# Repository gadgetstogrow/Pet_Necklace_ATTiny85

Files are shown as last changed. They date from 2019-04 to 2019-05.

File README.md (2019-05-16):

# USE THE RECONFIGURATION CODE - KG 5-16-19 (WILL MERGE BEFORE PUBLISHING)

# LED Pet Necklace with the ATTiny85

This project is useful for those looking to journey outside the cozy confines of the Arduino Uno and on to other AVRs. The ATTiny85 is a great place to start. The example code was first developed using Atmel Studio 7 with the help of an AVR Dragon for debugging. Don't worry, It will compile and upload using the Arduino IDE. A complete and detailed tutorial can be found on my project page on [Hackster.io] (https://www.hackster.io/GadgetsToGrow/)

## 3D Printed Parts

The 3D parts that make up the enclosure of this project were designed using [FreeCAD](https://www.freecadweb.org/) all other materials needed are available online or at your local hardware store.

## Concepts discussed on Hackster.io 

-Direct Register Manipulation - discover and experiment with the DDRB, PINB, PORTB and other registers of the ATTiny85 to control input and output instead of using the familiar pinMode() and digitalWrite() methods. We'll also be using register manipulation for Timer/Counter1 and the Analog to Digital Converter (ADC).

-Power Management - we'll use a coin cell battery for this project, so reducing unnecessary power consumption is paramount. (e.g. sleep mode and turning off peripherals we're not using).

-Pin Change Interrupts - the Tilt Sensor is used to wake up the ATTiny85 from sleep mode via a pin change interrupt using the PCINT0 vector. Why use power for the MCU and LEDs when your pet is sleeping or still?

-ADC Setup and Measurement - we'll leave analogRead() behind, and control the ADC to measure ambient light level through direct register control. You'll see how to handle a 10-bit value, and how to enable and disable the ADC for power management.
Timer/Counter1 - instead of tying up processor time with the mundane task of blinking LEDs at a specific interval, we'll use TImer/Counter1 to handle this task and explore the benefits of this "set it and forget it" methodology.

### Prerequisites

You'll need to use a USBTiny programmer, the ArduinoISP example code or similar method for programming an ATTiny85. These methods are beyond the scope of this project, but a vast amount of instruction is available online.
With that said, if you're planning on working with AVRs other than the Arduino (especially ones without a UART (like the ATTiny85) I'd highly recommend taking a look at Atmel Studio and a compatible programmer/debugger. Atmel Studio is free, and you can pick up an AVR Dragon on Ebay for < $50.

## License

This project is licensed under the GNU License - see the [LICENSE.md](LICENSE.md) file for details

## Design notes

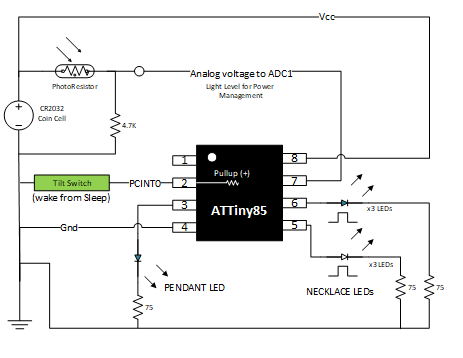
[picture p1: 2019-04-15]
Logic Flow Diagrams/Blinky Flashy Pet Collar Block Diagram.png

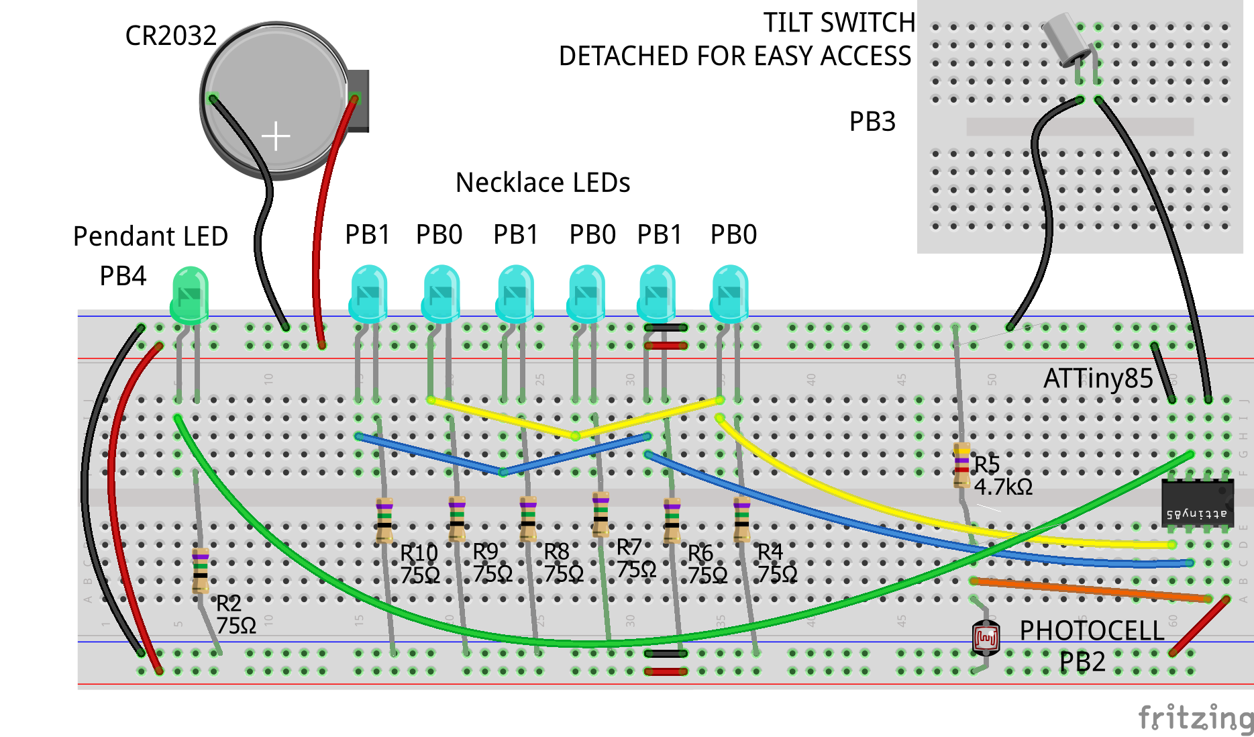
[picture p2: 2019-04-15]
Fritzing/Pet_Necklace_ATTiny85_Image.png

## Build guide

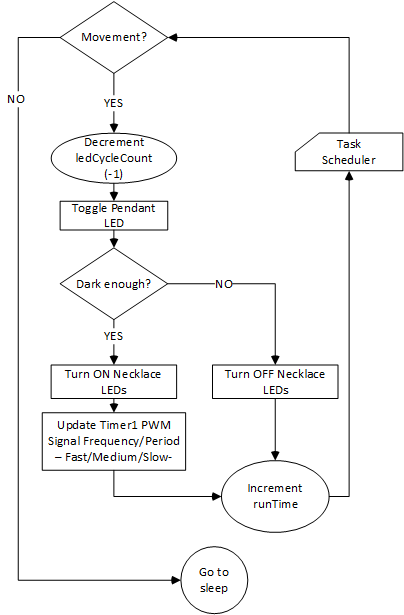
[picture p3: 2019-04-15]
Logic Flow Diagrams/Theory of Operation.png

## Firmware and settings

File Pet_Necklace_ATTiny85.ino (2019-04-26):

/****************************************************************************
 *  Project:	Pet_Necklace_ATTiny85.ino
 *	Version:	1.4.0
 *  Contact:	Kevin Gagnon
 *	Twitter:	@GadgetsToGrow
 *
 *  YouTube:	https://www.youtube.com/channel/UCseG_fDVFWgDqoBSpghMIPg
 *	  
 *  Date:		4-15-2019
 *  
 *  Purpose:	A *glamorous* blinking pet necklace using the ATTiny85. 
 *				Blinking occurs when the tilt/inclination sensor detects
 *				movement and only turns on the main LEDs (6) in the collar
 *				portion of the necklace when the light level is at a specified
 *				threshold. There is a pendant LED that will flash if there is
 *				movement, independent of the light level. When no movement is
 *				detected, the ATTiny85 is put into power down sleep mode and
 *				awaits an interrupt from the tilt sensor.
 *			
 *  Tutorial:	
 *
 *  Source:		
 * 
 *  ATTiny85 PINOUT *********************************************************
 *
 *	SOFTWARE	PHYSICAL
 *	PIN			PIN			PURPOSE											
 *	-------------------------------------------------------------------------
 *	PB0 - PB1:	5-6			Blink the 6 Necklace LEDs
 *  PB2:		7			PhotoCell (Power Management) Is it dark enough?	
 *	PB3:		2			Pin Change Interrupt (PCINT0_vect/PCINT3)
 *	PB4:		3			Pendant LED							
 *
 ****************************************************************************/

#include <avr/sleep.h>
#include <avr/io.h>
#include <avr/interrupt.h>

// ***
// *** Task Scheduler library
// ***
#include "Task.h"
#include "TaskScheduler.h"

// ***
// *** Application Configuration File (e.g. Pin Numbers, CPU Clock Frequency, etc.)
// ***
// ***
#include "Config.h"

// ***
// *** Application specific tasks
// ***
// Note: Necklace LEDs will only be turned on at certain light level threshold.
#include "Photocell.h"

// --------------------------------------------------------------------------------------------
// Define the AppManager Class as type: TimedTask
//
// Reads the ledCycleCount variable (incremented by ISR(PCINT0_vect) every 100ms
// via the tilt sensor attached to Pin PB3. If the value is greater than zero
// (activity sensed) the AppManager Task (depending on light level) executes LED routines.
//
// If ledCycleCount is zero (no activity/lazy pet), it puts the ATTiny85 to sleep and waits to be interrupted again. 
//
// --------------------------------------------------------------------------------------------
class AppManager : public TimedTask
{
	public:
		AppManager( uint16_t _readRate,	Photocell *_ptrPhotocell);
		//Task Scheduler-------------------------------------------------------------------------------			
		virtual void run(uint32_t now);
	
	private:
		uint8_t readRate; 						// Rate to read the Tilt Sensor
		
		//Tilt Sensor Related--------------------------------------------------------------------------
		void initPinChangeInterrupt();			// Enables the Pin Change Interrupt

		//ADC Related----------------------------------------------------------------------------------
		void enableADC(bool _enabled);			// Enable/Disable the ADC
		bool isLightLevelOk();					// Compare Light Level reading to LIGHT_THRESHOLD
		
		//Pendant LED----------------------------------------------------------------------------------
		void togglePendantLED();				//Toggle the Pendant LED on each read of Tilt Sensor
												//independent of the current Light Level.
		
		//Necklace LEDs--------------------------------------------------------------------------------
		void clearTimer1Config();
		void updateTimer1Config(uint8_t _ledCycleCount);	// Timer1: Change/Update Timer1 Mode/Rate
		void initAlternatingBlink_PWM();

		//Global Control-------------------------------------------------------------------------------
		void enableGlobalInterrupts(bool _enabled);		// Enable/Disable Global Interrupts sei/cli
		void enableNecklaceLEDOutput(bool _enabled);	// Enable/Disable Output for LEDs in Necklace
		void enablePendantLEDOutput(bool _enabled);		// Enable/Disable Output for the Pendant LED
		void goToSleep();								// Turn off peripherals and go to sleep...ZZzz
		
		//App Task Control Pointers-------------------------------------------------------------
		Photocell *ptrPhotocell;

};

//-------------------------------------------------------------------------------------------
// AppManager Constructor - Initializes the TimedTask to control the current application
//-------------------------------------------------------------------------------------------
AppManager::AppManager( uint16_t _readRate, Photocell *_ptrPhotocell)
	
	: TimedTask(millis()),
	readRate(_readRate),
	ptrPhotocell(_ptrPhotocell)

{
	
	// ***
	// *** Enable Tilt Sensor Pin Change Interrupt on PB3
	// ***
	initPinChangeInterrupt();

	// ***
	// *** Enable Global Interrupts - sei();
	// ***
	enableGlobalInterrupts(true);
	
	
	// ***
	// *** Enable Necklace LED Output (PB0/PB1)
	// ***
	enableNecklaceLEDOutput(true);
	
	// ***
	// *** Enable Pendant LED Output (PB4)
	// ***
	enablePendantLEDOutput(true);
		
	// ***
	// *** Clear Timer1 Configuration Settings
	// ***
	clearTimer1Config();
	
	// ***
	// *** Initialize Timer1 to handle LED control
	// ***
	initAlternatingBlink_PWM();

}

//-------------------------------------------------------------------
// Main AppManager Routine
//-------------------------------------------------------------------
void AppManager::run(uint32_t now)
{
	if(ledCycleCount > 1) //Movement/Awake - performing application functions
	{
		//Decrement  the ledCycleCount, when it finally reaches zero, go to sleep
		ledCycleCount--;

			// Toggle the LED in the Pendant. This is good for debugging and battery
			// monitoring even if the light level is too high for the Necklace LEDs.
			togglePendantLED();

			// Check the Light Level against LIGHT_THRESHOLD
			if(isLightLevelOk())
			{
				
				// Enable the Necklace LEDs on PB0 and PB1.
				enableNecklaceLEDOutput(true);
				
				// Update the Output Compare Registers (OCR1A and OCR1C) depending
				// on the current value of ledCycleCount to change the frequency and
				// period of outputs PB1/OC1A and PB0/!OC1A
				updateTimer1Config(ledCycleCount);
					
			} else {
					
				// Disable the Necklace LEDs on PB0 and PB1 to conserve power and leaves
				// the Pendant LED active and independent of the current light level
				// threshold. The Pendant will stop flashing when ledCycleCount reaches zero.
				enableNecklaceLEDOutput(false);
					
			} //End Light Level Check

	}
	else //ledCycleCount is Zero, go to Sleep
	{
		
		goToSleep();

	} //End ledCycleCount > 1 Check
	
	//Set the next time for the AppManger to execute its run() method
	incRunTime(readRate);
}


//-------------------------------------------------------------------
// LED Output Enable/Disable for the 6 Necklace LEDs
//-------------------------------------------------------------------
void AppManager::enableNecklaceLEDOutput(bool _enabled)
{
	
	//DATASHEET REFERENCE:
	/*************************************************************************
	* Port B Data Direction Register (DDRB) (Datasheet 10.2.1, Pg: 54)
	*
	* |  -  |  -  |DDB5 |DDB4 |DDB3 |DDB2 |DDB1 |DDB0 |
	* | N/A | N/A |  0  |  0  |  0  |  0  |  0  |  0  |
	**************************************************************************
	* Port B Data Register (PORTB) (Datasheet 10.2.1, Pg: 54)
	*
	* |  -  |  -  | PB5 | PB4 | PB3 | PB2 | PB1 | PB0 |
	* | N/A | N/A |  0  |  0  |  0  |  0  |  0  |  0  |
	**************************************************************************/

	if(_enabled)
	{
		//Set pins to output
		DDRB |= (1 << NECKLACE_LED_0);		//PB1
		DDRB |= (1 << NECKLACE_LED_1);		//PB0
		
	} else {
		
		//Make sure LEDs are off
		PORTB &= ~(1 << NECKLACE_LED_0);	//write LOW/0 to PB0
		PORTB &= ~(1 << NECKLACE_LED_1);	//write LOW/0 to PB1
		
		//Set pins to input
		DDRB &= ~(1 << NECKLACE_LED_0);		//PB0
		DDRB &= ~(1 << NECKLACE_LED_1);		//PB1

	}	
}

//-------------------------------------------------------------------
// LED Output Enable/Disable for the 6 Necklace LEDs
//-------------------------------------------------------------------
void AppManager::enablePendantLEDOutput(bool _enabled)
{
	
	//DATASHEET REFERENCE:
	/*************************************************************************
	* Port B Data Direction Register (DDRB) (Datasheet 10.2.1, Pg: 54)
	*
	* |  -  |  -  |DDB5 |DDB4 |DDB3 |DDB2 |DDB1 |DDB0 |
	* | N/A | N/A |  0  |  0  |  0  |  0  |  0  |  0  |
	**************************************************************************
	* Port B Data Register (PORTB) (Datasheet 10.2.1, Pg: 54)
	*
	* |  -  |  -  | PB5 | PB4 | PB3 | PB2 | PB1 | PB0 |
	* | N/A | N/A |  0  |  0  |  0  |  0  |  0  |  0  |
	**************************************************************************/

	if(_enabled)
	{
		//Set pin to output
		DDRB |= (1 << PENDANT_LED);			//PB4
		
	} else {
		
		//Make sure LEDs are off
		PORTB &= ~(1 << PENDANT_LED);		//write LOW/0 to PB4
		
		//Set pins to input
		DDRB &= ~(1 << PENDANT_LED);		//PB0

	}	
}


//-------------------------------------------------------------------
// Toggle the Pendant LED (unaffected by light level)
// Blinks at a steady 100ms when ledCycleCount > 0
//
// DATASHEET REFERENCE:
// Using the PINB register to Toggle a Pin: Paragraph 10.2.2, Pg: 54
//-------------------------------------------------------------------
void AppManager::togglePendantLED()
{
	// *** 
	// *** Quick and easy method to change the state of an LED. If it
	// *** is on, it will turn it off and vice-versa.
	PINB |= (1 << PB4);
}

//---------------------------------------------------------------------------
// Adjust Frequency/Period and Duty Cycle of Timer1 - proportional to the
// ledCycleCount: more activity = faster rate
//---------------------------------------------------------------------------
void AppManager::updateTimer1Config(uint8_t _ledCycleCount)
{
	
	if (_ledCycleCount > CYCLE_RATE_THRESHOLD_FAST)
	{			
			//***********************************************************
			//***********************************************************
			// Prescaler Clock is set to:
			// Frequency 488.28Hz
			//
			// Equation: (Refer to initAlternatingBlink_PWM() method)
			//
			// 8000000/16824 = 488.28Hz <--- 8MHz System Clock
			//		or
			// 1000000/2048	= 488.28Hz	<--- 1MHz System Clock
			// 
			// (One Clock Tick = 2.048ms)
			//
			// 
			//***********************************************************
			//***********************************************************	
			//***********************************************************
			//	CYCLE_RATE_THRESHOLD_FAST:
			//
			//	Frequency:	~10Hz
			//
			//	Equation:
			//	488.28 / OCR1C=[49 + 1] = 9.77Hz
			//-----------------------------------------------------------
			//  Period:		~100ms
			//
			//  Equation: 
			//	1 Clock Tick=[2.048ms] x OCR1C=[49 + 1] = 102.4ms
			//***********************************************************
			OCR1C = 49;

			//***********************************************************				
			//	Duty Cycle:	~50%  <-- ON for 1/2 of period
			//	
			//	Equation:
			//	OCR1A=[24 + 1] / OCR1C=[49 + 1] = .50
			//***********************************************************
			OCR1A = 24;	
				
	} else if ((_ledCycleCount <= CYCLE_RATE_THRESHOLD_FAST) 
				&& (_ledCycleCount > CYCLE_RATE_THRESHOLD_MEDIUM))
	
		{
			//***********************************************************
			//	CYCLE_RATE_THRESHOLD_MEDIUM:
			//
			//	Frequency:	~5Hz
			//
			//	Equation:
			//	488.28Hz / OCR1C=[99 + 1] = 4.88Hz
			//-----------------------------------------------------------
			//  Period:		~200ms
			//
			//  Equation: 
			//	1 Clock Tick=[2.048ms] x OCR1C=[99 + 1] = 204.8ms
			//***********************************************************
			OCR1C = 99;

			//***********************************************************				
			//	Duty Cycle:	~50%  <-- ON for 1/2 of period
			//	
			//	Equation:
			//	OCR1A=[49 + 1] / OCR1C=[99 + 1] = .50
			//***********************************************************	
			OCR1A = 49;
				
	} else {	
				
			//***********************************************************
			//	CYCLE_RATE_THRESHOLD_SLOW:
			//
			//	Frequency:	~2.5Hz
			//
			//	Equation:
			//	488.28Hz / OCR1C=[199 + 1] = 2.44Hz
			//-----------------------------------------------------------
			//  Period:		~400ms
			//
			//  Equation: 
			//	1 Clock Tick=[2.048ms] x OCR1C=[199 + 1] = 409.6ms
			//***********************************************************	
			OCR1C = 199;		
      //***********************************************************       
      //  Duty Cycle: ~50%  <-- ON for 1/2 of period 
      //
      //  Equation:
      //  OCR1A=[99 + 1] / OCRIC=[199 + 1] = .50
      //*********************************************************** 
      OCR1A = 99;				
	} 

}

void AppManager::clearTimer1Config()
{
	TCCR1 = 0;
	GTCCR = 0;
	OCR1A = 0;
	OCR1B = 0;
	OCR1C = 0;
	TCNT1 = 0;
	
}

void AppManager::initAlternatingBlink_PWM()
{
	//-------------------------------------------------------------------------------------------
	//Alternating PWM pulses via Timer/Counter1
	//-------------------------------------------------------------------------------------------
		/****************************************************************************************
		* TCCR1 � Timer/Counter1 Control Register Figure: 12.3.1, Pg: 89)
		*		CTC1 - Clear Timer/Counter1 on Compare Match (CTC Mode)
		*		CTC1 - Clear Timer/Counter1 on Compare Match (CTC Mode)
		*		PWM1A - Pulse Width Modulator A Enable (PMW)
		*		COM1A[1:0] - Controls output on OC1A/PB1
		*		CS[13:10] - Clock Select bits (refer to Table: 12-5, Pg: 89)
		*
		* Compare Output Mode, Fast PWM (Datasheet Table: 11-3, Pg: 78)
		*
		* |COM1A1 |COM1A0 |
		* |	  0   |   0   | <-- OC1A/PB1 Disconnected
		* |   0   |   1   | <-- Toggle OC1A/PB1
		* |   1   |   0   | <-- Clear OC1A/PB1 output line
		* |   1   |   1   | <-- Set OC1A/PB1 output line
		*
		* Note: Clock Select CS[12-10] is global to Timer/Counter1 and affects both OC1A/PB1 
		* and OC1B/PB4. We set the Prescale clock to 488.28ms
		* 
		*
		* |CTC1 |PWM1A|COM1A1 |COM1A0 |CS13 |CS12 |CS11 |CS10|
		* |  1  |  0  |   0   |   0   |  0  |  1  |  0  |  0 |  < - 
 		*****************************************************************************************/
		TCCR1 = 
				(0 << CTC1)		|	//PWM 
				(1 << PWM1A)	|	//PWM 
				(0 << COM1A1)	|	//OC1A/PB1 
				(1 << COM1A0)	|	//OC1A/PB1 
		#if F_CPU == 1000000UL		// <-----------Divide System Clock by 2048 
				(1 << CS13)		|	//CS bit 3
				(1 << CS12)		|	//CS bit 2
				(0 << CS11)		|	//CS bit 1
				(0 << CS10);		//CS bit 0
		#elif F_CPU == 8000000UL	// <-----------Divide System Clock by 16384
				(1 << CS13)		|	//CS bit 3
				(1 << CS12)		|	//CS bit 2
				(1 << CS11)		|	//CS bit 1
				(1 << CS10);		//CS bit 0
		#endif

}

// ---------------------------------------------------------------------
// Enable PCINT3 on PB3 for ATTiny85
//		-Pin Change (Only LOW increments ledCycleCount via the MOVEMENT macro in Config.h
//		-Fires ISR(PCINT0_vect) on ATTiny85
// ---------------------------------------------------------------------
void AppManager::initPinChangeInterrupt()
{
	/****************************************************************************************
	* Set up Tilt Sensor to Input - Replaces: "pinMode(PB3, INPUT)" 
	*****************************************************************************************
	* Port B Data Direction Register (DDRB) (Datasheet 10.4, Pg: 64)
	* Set DDB3 to zero.
	*
	* |  -  |  -  |DDB5 |DDB4 |DDB3 |DDB2 |DDB1 |DDB0 |
	* | N/A | N/A |  0  |  0  |  0  |  0  |  0  |  0  |
	****************************************************************************************/
	DDRB  &= ~(1 << TILT_SENSOR_PIN);	//Set TILT_SENSOR_PIN(PB3) to Input -DDB3/PB3 = 0
	
	/****************************************************************************************
	* Set up Tilt Sensor Input as a Pullup Pin - Replaces: "digitalWrite(PB3, HIGH)"
	*****************************************************************************************
	* Port B Data Register (PORTB) (Datasheet 10.4, Pg: 64)
	* Set PORTB3 to one (1)
	*
	* |  -  |  -  |PORTB5 |PORTB4 |PORTB3 |PORTB2 |PORTB1 |PORTB0 |
	* | N/A | N/A |   0   |   0   |   1   |   0   |   0   |   0   |
	****************************************************************************************/	
	PORTB |= (1 << TILT_SENSOR_PIN);		//Enable the pull-up resistor on PORTB3/PB3 = 1


	// -----------------------------------------------------------------
	// Enable Pin Change Interrupt on TILT_SENSOR_PIN/PB3/PCINT3
	// -----------------------------------------------------------------
	
	/****************************************************************************************
	* GIMSK - General Interrupt Mask Register (DataSheet Figure: 9.3.2, Pg: 51)
	*
	*
	* |  -  |INT0 |PCIE |  -  |  -  |  -  |  -  |  -  |
	* | N/A |  0  |  1  | N/A | N/A | N/A | N/A | N/A |
	*****************************************************************************************/
	GIMSK = 
			(0 << INT0) |	//Disable External Interrupts
			(1 << PCIE);	//Enable Pin Change Interrupts

	/****************************************************************************************
	* PCMSK - Pin Change Mask Register (DataSheet Figure: 9.3.4, Pg: 52)
	*
	*
	* |  -  |  -   |PCINT5|PCINT4|PCINT3|PCINT2|PCINT1|PCINT0|
	* | N/A | N/A  |  0   |  0   |  1   |  0   |  0   |  0   |
	*****************************************************************************************/

	PCMSK = 
			(0 << PCINT5)			|
			(0 << PCINT4)			|
			(1 << TILT_SENSOR_PIN)	|  //Use PB3 as interrupt pin PCINT3
			(0 << PCINT2)			|
			(0 << PCINT1)			|
			(0 << PCINT0);
}		

// ---------------------------------------------------------------------
// Enable Global Interrupts in SREG
// ---------------------------------------------------------------------
void AppManager::enableGlobalInterrupts(bool _enabled)
{
	if(_enabled)
	{
		
		sei();
		
	} else {
		
		cli();
	}
	
}



// ---------------------------------------------------------------------
// Enable/Disable the ADC (disabled before sleep, then re-enabled on wakeup
// for power management considerations.
// ---------------------------------------------------------------------
void AppManager::enableADC(bool _enabled)
{
	if(_enabled)
	{

		ADCSRA = (1 << ADEN);

		} else {
		
		ADCSRA = (0 << ADEN);
		
	}
}


// ---------------------------------------------------------------------
// Put the ATTiny into deep sleep when no movement is detected
// ---------------------------------------------------------------------
void AppManager::goToSleep()
{
		// ***
		// *** Disable Global Interrupts First
		// ***
		enableGlobalInterrupts(false);
		
		// ***
		// *** Clear the ledCycleCount variable
		// ***
		ledCycleCount = 0;
		
		// ***
		// *** Disable LED Outputs (Power Management)
		// ***
		enablePendantLEDOutput(false);
		enableNecklaceLEDOutput(false);
		
		// ***
		// *** Turn off the Analog To Digital Converter (ADC) 
		// ***
		enableADC(false);

		// ***
		// *** Sleep Mode: Deep Sleep
		// ***
		set_sleep_mode(SLEEP_MODE_PWR_DOWN);
		sleep_enable();
		
		// ***
		// *** Enable Global Interrupts -to wake up from sleep PCINT0 on TILT_SENSOR_PIN/PB3/PCINT3
		// ***
		enableGlobalInterrupts(true);
		
		// ***
		// *** Go to sleep
		// ***
		//ZZZZZZZZZZZZZZZZZZZZZZZZZZZZZZZZZZZZZZZZZZZZZZZZZZZZZZZZZZZZZZZZZZZZZZZZZZZZZZZZ
		//ZZZZZZZZZZZZZZZZZZZZZZZZZZZZZZZZZZZZZZZZZZZZZZZZZZZZZZZZZZZZZZZZZZZZZZZZZZZZZZZZ
		sleep_mode();
		//ZZZZZZZZZZZZZZZZZZZZZZZZZZZZZZZZZZZZZZZZZZZZZZZZZZZZZZZZZZZZZZZZZZZZZZZZZZZZZZZZ
		//ZZZZZZZZZZZZZZZZZZZZZZZZZZZZZZZZZZZZZZZZZZZZZZZZZZZZZZZZZZZZZZZZZZZZZZZZZZZZZZZZ
		// ***
		// *** Wake Up
		// ***
		sleep_disable();
		
		// ***
		// *** Turn On the Analog To Digital Converter (ADC) for Photocell readings
		// *** 
		enableADC(true);

		//Re-enable Output LEDs
		enablePendantLEDOutput(true);
		enableNecklaceLEDOutput(true);
		
}

// ---------------------------------------------------------------------
// Check the latest Light Level via ADC/Photocell and compare to our
// predetermined threshold.
// ---------------------------------------------------------------------
bool AppManager::isLightLevelOk()
{
	
	//Use the pointer to the Photocell object to retrieve the latest reading
	//and compare it to the threshold set in Config.h
	return (ptrPhotocell->getLightLevel() < LIGHT_THRESHOLD);

}
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
void loop() 
{

/***************************************************************************************
* Description:  Instantiate the tasks and schedule task priority.
* Purpose:		This is the heart of the program.  All of the needed code has been 
*				encapsulated in the above Class definitions. The code below will
*				create the task objects based on these classes and fill a task
*				array for the TaskScheduler to manage.
*
*
* Note:     Although this is located in the loop() routine, this will only
*			run once. TaskScheduler::run() never returns control to loop().
*
***************************************************************************************/

// ***
// *** Instantiate the task objects for use by the TaskScheduler
// ***

	Photocell photocell(PHOTOCELL_PIN, PHOTOCELL_READ_RATE_MS);
	
	AppManager appManager(APP_MANAGER_RATE_MS, &photocell);

 // ***
 // *** Create an array of reference addresses to the task objects we just instantiated.
 // ***
 // *** The order matters here.  When the TaskScheduler is running it finds the first task it can
 // *** run--canRun(), runs the task--run(), then returns to the top of the list and starts the
 // *** process again.
 // ***

Task *tasks[] = {
	&appManager,
	&photocell

  
};

 //***
 //*** Instantiate the TaskScheduler and fill it with task references.
 //***
 TaskScheduler scheduler(tasks, NUM_TASKS(tasks));
 
 //GO! Run the scheduler - it never returns.
 scheduler.runTasks();
  
}

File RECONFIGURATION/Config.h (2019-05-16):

/*************************************************************************************************
 * Config.h
 * 
 * Purpose: Configuration Settings for the Pet_Necklace_ATTiny85 application
 * 
 * 
 * Copyright � 2019 Kevin Gagnon. All Rights Reserved.
 *
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
 * You should have received a copy of the GNU General Public License
 * along with the Task Scheduler example code. If not,
 * see http://www.gnu.org/licenses/.
 ************************************************************************************************/ 

#ifndef CONFIG_H_
#define CONFIG_H_

//-------------------------------------------------------------------
// ATTiny85 fuse settings are set for 1MHz clock speed for power conservation.
// Note: the code is configured to run with both a 1MHz and 8MHz clock, and 
// will adjust according to the below (uncommented) definition. If you use the USBTiny to 
// program the ATTiny85, make sure you "Burn Bootloader" to set the appropriate
// fuses.
//-------------------------------------------------------------------
//#define F_CPU 1000000UL
//#define F_CPU 8000000UL

//-------------------------------------------------------------------
//
// Pin Definitions
//								Software		Device	Purpose
//								Pin				Pin			
//-------------------------------------------------------------------
#define TILT_SENSOR_PIN			PB3			//	2		Tilt Switch Interrupt Pin
#define PHOTOCELL_PIN			PB2			//	7		Light Level via Photocell
#define NECKLACE_LED_0			PB0			//  5		!OC1A - Timer1 (inverted)
#define NECKLACE_LED_1			PB1			//	6		OC1A - Timer1
#define PENDANT_LED				PB4			//  3		Blinks at AppManager Read Rate

//------------------------------------------------------------------
// Only increment ledCycleCount on a LOW (0) from tilt sensor
//------------------------------------------------------------------
#define MOVEMENT !(PINB & (1 << TILT_SENSOR_PIN))

//-------------------------------------------------------------------
// Volatile variable for Pin Change Interrupt PCINT2_vect ISR on PB3
// When the tilt sensor detects movement, this interrupt is fired and the 
// ledCycleCount variable is incremented.  The AppManager Task decrements
// this variable at a predefined rate.
//-------------------------------------------------------------------
volatile uint8_t ledCycleCount = 0;

// -----------------------------------------------------------------
//
// TimedTask Default Cycles 
//
// Note:	The rates below will vary based on the F_CPU setting above,
//			and provide similar operational results independent of system
//			clock speed (1MHz or 8MHz).
//
//									Rate  Purpose
//-------------------------------------------------------------------
#define APP_MANAGER_RATE_MS		100   // ~100 milliseconds readRate 
#define PHOTOCELL_READ_RATE_MS  1000  // ~1 second

//-------------------------------------------------------------------
// LED Cycle Count/Thresholds (ledCycleRate)
//-------------------------------------------------------------------
#define CYCLE_RATE_THRESHOLD_FAST	60	//ledCycleCount 100-60
#define CYCLE_RATE_THRESHOLD_MEDIUM	20	//ledCycleCount 59-20
#define CYCLE_RATE_THRESHOLD_SLOW	0	//ledCycleCount 19-0

//-------------------------------------------------------------------
// Cycle Count Definitions (ledCycleCount)
//-------------------------------------------------------------------
#define CYCLE_INCREMENT_BY_X		1	//Increment the ledCycleCount by...
#define CYCLE_COUNT_MAX				100	//Max ledCycleCount (no debounce)

//-------------------------------------------------------------------
// ADC variables (light level - 8 bit resolution)
//
// Power Management: Experiment with the LIGHT_THRESHOLD value to meet 
// your power management needs. The lower this number is, the lower the
// light level has to be, to turn on the necklace LEDs. The Pendant LED
// will remain unaffected until the ledCycleCount reaches zero.
//-------------------------------------------------------------------
enum lightThresholds {DARK = 10, SUNDOWN = 40, TWILIGHT = 70};

#define LIGHT_THRESHOLD	 SUNDOWN

#endif /* CONFIG_H_ */

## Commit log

2019-04-15 Initial Commit of Pet_Necklace_ATTiny - Part 1
    Hackster.io Project: Pet Necklace ATTiny85 - Part 1
    [Pet_Necklace_ATTiny85.fzz]
2019-04-26 Pin Change Fix

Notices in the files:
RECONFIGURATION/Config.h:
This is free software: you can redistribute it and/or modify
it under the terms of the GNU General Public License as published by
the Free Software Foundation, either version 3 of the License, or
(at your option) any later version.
